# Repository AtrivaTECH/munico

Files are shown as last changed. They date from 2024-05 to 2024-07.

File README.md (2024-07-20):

# μNico
All files for the μNico series of boards!
1 - Copy

## Licensing
oshw_facts

## Tools Utilised

kicad-1

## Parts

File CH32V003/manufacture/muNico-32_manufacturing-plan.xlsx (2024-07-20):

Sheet: BOM-muNico
Sno | Part | Qty | Total | Cost | Total Cost | Supplier
1 | Ch32V003 | 1 | 120 | 31.9 | 3828 | Hubtronics
2 | Green LED 0603 | 1 | 120 | 0.48 | 57.6 | Ktron
3 | Resistor | 1 | 120 | 0.16 | 19.2 | Ktron
4 | AMS1117 | 1 | 120 | 2.98 | 357.6 | Ktron/Kasturi Electrosales | Costs are in INR unless mentioned.
5 | ressitor-usb | 1 | 120 | 0.16 | 19.2 | Ktron
6 | 2.5 Headers | 2 | 240 | 5.5 | 1320 | Ktron
7 | Bootsel SW | 1 | 120 | 20 | 2400 | DK
 |  | TOTAL |  |  | 8001.6
 |  | Per Piece |  |  | 66.68

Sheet: muNico Cost split
 |  | Cost per muNico |  |  | Note
Sno | Item | Cost/piece | QTY | Amount | 120 pieces is minimum as cost is approprably lower at said cost.
1 | Components | 66.68 | 120 | 5601.6
2 | PCB | 46.01666667 | 120 | 5522 | PCB Made locally at PCB Power, Gujarat | LEGEND
3 | Assembly | 20 | 120 | 2400 |  |  | Can Be ignored
4 | ESD Cover | 2.5 | 120 | 300 |  |  | Raw Costs
5 | Sticker | 5 | 120 | 600 |  |  | Set cost and calculations
6 | Stencil | 10 | 120 | 1200 | Cost of one stencil is split across 120 devices |  | Cost in USD per piece including profits, etc etc
 | Cost | 150.1966667 |  | 15623.6 | Estimated cost of manufacture for muNico boards alone |  | Important Note
 | NRE | 3.003933333 |  |  |  |  | Generic Point of note.
 | NET Cost of Manufacture | 153.2006 |  |  |  | Costs are in INR unless mentioned.
 | Expected Cost | 220
 | Cost to be Set | 335
 | Profit % for set | 118.6675509
 | Profit for expected % | 43.60257075
 | Cost after MarkUp | 291.11
 | USD $ per piece (Cost that is set. Not cost of manufacture) | $4.03

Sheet: Cost Allocation
S No | Part/Service | Cost Allocated | Total | QTY | Note
1) | Raw Parts | ₹8002.00 | ₹8002.00 | 120 | 120 pieces chosen for appropriate price ratio.
2) | PCBs (H Extender) | ₹4460.00 | ₹4460.00 | 60
3) | PCBs muNico | ₹5522.00 | ₹5522.00 | 120
4) | muNico Assembly | ₹2400.00 | ₹2400.00 | 120
5) | Packaging-ESD Covers | ₹300.00 | ₹300.00 | 120 |  | Costs are in INR unless mentioned.
6) | Packaging- Box * | ₹1000.00 | ₹1000.00 | 50 | Only Applicable to bundles (variable cost) Approx ₹20 per bx
7) | Sticker/Card for muNico Pack) | ₹600.00 | ₹600.00 | 120 | Raw Material
8) | Assembly Stencil | ₹1200.00 | ₹1200.00 | 1 | For Assembly of each muNico board
9) | WCH LinkEs | ₹14000.00 | ₹14000.00 | 20 | To obtain minimum quantity of programmers. If number required will be lesser than amount specified here, excess amount will be re-invested.
10) | Printing of sticker | ₹2600.00 | ₹2600.00 | 120+20 | Printing on cards+stickers
11) | Customs Clearance/White paper/Shipping | ₹10000.00 | ₹10000.00 |  | To Cover Shipping from India to US, customs and possible extra charges during export
12) | Emergency Costs | ₹8000.00 | ₹8000.00 |  | For covering any damaged parts/PCBs/IC's/ Covers/Boxes ~15%
14) | RoHS Compatible lead free paste | ₹2500 | ₹2500.00
 | TOTAL |  | ₹60584.00 |  | Includes final costs for both munico boards and bundles
 | Total in USD |  | $738.83 | Total Campaign cost excluding any cuts.
 |  |  |  |  | NOTE: Costs of Shipping and Customs will lower core campaign cost if handled partially/fully by Mouser
 |  |  |  |  | NOTE3: If RoHS or CE/UKCA is considered although a development board, then an additional 150USD to RoHS (via SGS) and 400,000 INR is required for UKC/CE and 500,000 INR for FCC. As per quote from SGS and TUV SUD.

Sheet: Bundles
BUNDLE 1 (Starter) * |  |  |  |  | BUNDLE 2 (Hobbyist) * |  |  |  |  | BUNDLE 3 (Developer) |  |  |  |  | BUNDLE 4 (Developer +) |  |  |  |  | BUNDLE 5 (Professional)
S No | Part | Qty | MRP | Cost | S No | Part | Qty | MRP | Cost | S No | Part | Qty | MRP | Cost | S No | Part | Qty | MRP | Cost | S No | Part | Qty | MRP | Cost
1 | muNico | 1 | 335 | 335 | 1 | muNico | 2 | 670 | 670 | 1 | muNico | 2 | 670 | 670 | 1 | muNico | 4 | 1340 | 1300 | 1 | muNico | 10 | 3350 | 3200
2 | muNico Extender | 1 | 80 | 80 | 2 | muNico Extender | 1 | 80 | 80 | 2 | muNico Extender | 1 | 80 | 80 | 2 | muNico Extender | 2 | 160 | 80 | 2 | muNico Extender | 3 | 240 | 200
 |  |  |  |  |  |  |  |  |  | 3 | WCH link E | 1 | 700 | 700 | 3 | WCH link E | 1 | 700 | 700 | 3 | WCH link E | 1 | 700 | 700
Total Cost(Excluding Profits and Additionals) |  |  |  | 415 | Total Cost(Excluding Profits and Additionals) |  |  |  | 750 | Total Cost(Excluding Profits and Additionals) |  |  |  | 1450 | Total Cost(Excluding Profits and Additionals) |  |  |  | 2080 | Total Cost(Excluding Profits and Additionals) |  |  |  | 4100
Final Cost |  |  |  | 500 | Final Cost |  |  |  | 832 | Final Cost |  |  |  | 1664 | Final Cost |  |  |  | 2412 | Final Cost |  |  |  | 4574
USD |  |  |  | $6 | USD |  |  |  | $10 | USD |  |  |  | $20 | USD |  |  |  | $29 | USD |  |  |  | $49.29
CS Share | 12% | 0.72 |  |  | CS Share | 12% | 1.2 |  |  | CS Share | 12% | 2.4 |  |  | CS Share | 12% | 3.48 |  |  | CS Share | 12% | 5.9148
Final Cost (Incl Profits and Additionals) USD** |  |  |  | 6.72 | Final Cost (Incl Profits and Additionals) USD |  |  |  | 11.2 | Final Cost (Incl Profits and Additionals) USD |  |  |  | 22.4 | Final Cost (Incl Profits and Additionals) USD |  |  |  | 32.48 | Final Cost (Incl Profits and Additionals) USD |  |  |  | 55.2048
 |  |  | Costs are in INR unless mentioned.
 |  |  | * Bundle 1 and 2 may not be available in crowdfunding as they are low margin for possible distribution possibilities. In that Case, Bundle 3 Shall be renamed as Hobbyist.
 |  |  | ** This cost is assuming CS takes a cut per product. If the cut is net from the total campaign cost, caluclations will change. Or if CS takes a flat cost due to nature of campaign, cost will vary.

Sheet: Timeline
Tentative dates maximum by which processes must start/end. This is to accommodate around certain pre-set events.
S No | Task | Start Date | End Date | Deviation | Actual End Date | Note
1) | muNico Design | 2024-05-10 | 2024-05-20 | 1 Day Early | 2024-05-19 | Design process in KiCad
2) | muNico Prototype 1 | 2024-05-20 | 2024-05-31 | 1 Day Early | 2024-05-30 | First Prototyping of Board.
3) | prototype Testing | 2024-05-31 | 2024-06-01 | 2 Days Early | 2024-05-30 | Testing of First Prototype design
4) | Firmware/Examples Development | 2024-06-05 | 2024-06-17 | On Time Start | NaN
5) | Documentation | 2024-06-11 | 2024-06-23 | 2 Days Late Start | NaN | Tentative first edition publication date: 15-Jun Tentative Final Edition Publication Date: 25-Jun
6) | CS Campaign selection | 2024-08-10 | NaN | NaN | NaN | Tentative date by which product must be selected by CS. Earlier the better. This will help decide the next steps to be taken depending on decision
7) | Product Shipment to CS for testing Etc | 2024-08-15 | NaN | NaN | NaN | Product Shipment to CS for testing/Photogrpahy etc if necessary to be done maximum before set date.
8) | muNico Example Video (4) (or) split into Quick Start Guides | 2024-08-15 | 2024-08-17 | NaN | NaN | 4 Separate videos going in-depth into each programming and application method shall be made
9) | Examples- Video Production | 2024-08-17 | 2024-08-18 | NaN | NaN
 | Campaign | 2024-08-17 | NaN | NaN | NaN | Date by which campaign must start. To ensure timely completion
10) | First Production Run | 1 Day after campaign | 7 Days after Campaign | NaN | NaN | Production/Assembly of first lot of muNicos.Includes assembly overtime
11) | Accessories Order Run | 8 Days After | 10 Days After | NaN | NaN | All peripherals including Boxes, Covers etc that are to be ordered.
12) | Packaging Completion | 11 Days After | 15 Days After | NaN | NaN | Final Packaging of all goods in respectiove packaging to be completed.
13) | Shipment to Mouser | 16 Days After | NaN | NaN | NaN | Final Shipment Date (Tentative)
 | NOTE: CE/UKCA/FCC is not considered as it is a developnment board and not a commerical device meant for daily use or anything similar. Hence its cost and additionals are not considered.
 |  | Preferably Red-Tape Etc concludes before second week of July and does not extend. | Point 10 onwards are just tentative dates. These might change depending on no of orders and more. | NOTE: Marketing and promotional will happen parallely

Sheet: differentiation
Feature | muNico | CH32V003 Development Board | CH32V003 EVT | CH32V003 core demo board
MFR | AtrivaTECH | nanoDyne | WCH | WeAct
Chipset | CH32V003F4P6 | CH32V003F4U6 | CH32V003F4P6 | CH32V003F4U6
Intended Use | Portable Hardware hacking/USB control | Prototyping | Prototyping | Cheap prototyping
USB Port | USB A | USB C | USB C (power Only) | USB C (power Only)
Data | Yes | Yes | No | No
Dimensions | 19*14.5mm | 16*26mm | 39*45mm | 17.78*30.48mm |  | Legend
Clock | 2Mhz (Can be Expanded) | 12Mhz | 12 Mhz | 2Mhz (No expansion) |  |  | Pros
USB Host Capability | Yes | Yes | No | No |  |  | Not a Pros
Voltage Regulator | 3.3V (V-IN Capability) | 3.3V | No | No |  |  | Cons
External Switch (programmable) | Yes | Yes | No | No
External Enclosure | Yes (Additional) | No | No | No
Documentation | Custom baord specific documentation with use-cases, how-to guides and quick start guide | Limited to GitHub and Docs provided by WCH | No (Development board specific guides) | No documentation
Open Source | Yes OSHW IN53 | Yes | Yes (Limited to Schematic) | No direct linking to board files
Link | muNico 32 - by AtrivaTECH (https://atrivatech.com/munico-32/) | AlexanderMandera/CH32V003-USB-DevBoard: USB-capable Development Board for the CH32V003 microcontroller (github.com) (https://github.com/AlexanderMandera/CH32V003-USB-DevBoard) | CH32V003 Development Board Kit 32-bit general-purpose RISC-V MCU Functional application assessment (aliexpress.com) (https://www.aliexpress.com/item/1005005269690018.html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) | WeAct Studio CH32V003F4U6 RISC-V Low Power Core Demo Board - Robu.in | Indian Online Store | RC Hobby | Robotics (https://robu.in/product/weact-studio-ch32v003f4u6-risc-v-low-power-core-demo-board/) | ghgh
Cost | $4.03 | $4.68 | $3.21 | $1.43

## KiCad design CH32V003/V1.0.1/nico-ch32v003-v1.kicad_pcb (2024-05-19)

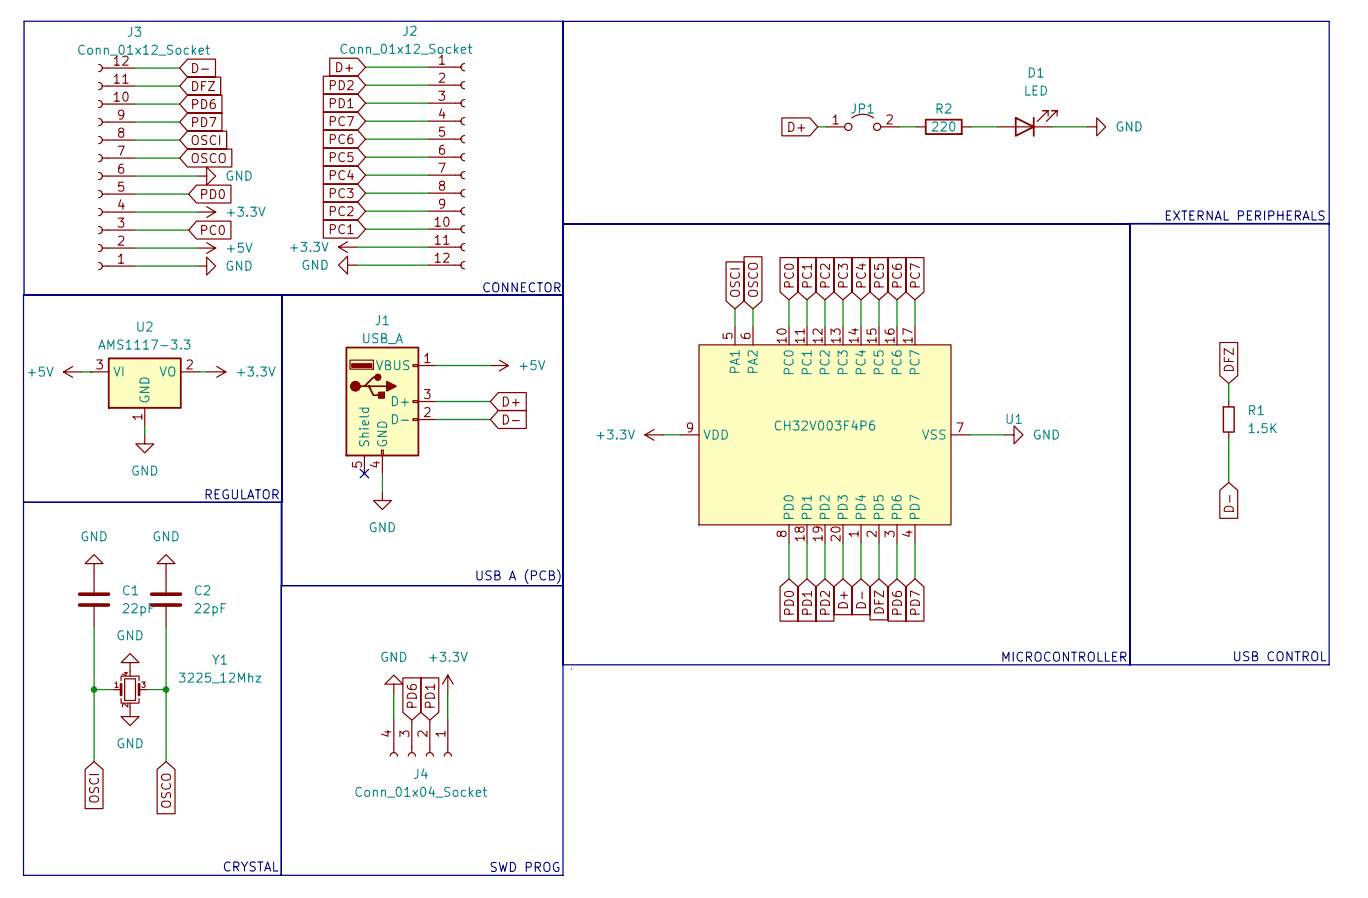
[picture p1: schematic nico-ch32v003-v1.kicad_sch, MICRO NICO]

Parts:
C1, C2: 22pF; C_0402_1005Metric_Pad0.74x0.62mm_HandSolder
D1: LED; LED_0603_1608Metric
J1: USB_A; usb-PCB
J2, J3: Conn_01x12_Socket; pads-1*12
J4: Conn_01x04_Socket; pads__1x04
JP1: Jumper_2_Open; jumper-2-open
R1: 1.5K; R_0402_1005Metric_Pad0.72x0.64mm_HandSolder
R2: 220; R_0402_1005Metric
U1: CH32V003F4P6; TSSOP-20_4.4x6.5mm_P0.65mm
U2: AMS1117-3.3; SOT-223-3_TabPin2
Y1: 3225_12Mhz; Crystal_SMD_3225-4Pin_3.2x2.5mm

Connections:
+3.3V: J2.11, J3.4, J4.1, U1.9 (VDD), U2.2 (VO)
+5V: J1.1 (VBUS), J3.2, U2.3 (VI)
D+: J1.3 (D+), J2.1, JP1.1 (A), U1.20 (PD3)
D-: J1.2 (D-), J3.12, R1.2, U1.1 (PD4)
DFZ: J3.11, R1.1, U1.2 (PD5)
GND: C1.1, C2.1, D1.1 (K), J1.4 (GND), J2.12, J3.1, J3.6, J4.4, U1.7 (VSS), U2.1 (GND), Y1.2, Y1.4
unnamed: D1.2 (A), R2.2
unnamed: JP1.2 (B), R2.1
OSCI: C1.2, J3.8, U1.5 (PA1), Y1.1
OSCO: C2.2, J3.7, U1.6 (PA2), Y1.3
PC0: J3.3, U1.10 (PC0)
PC1: J2.10, U1.11 (PC1)
PC2: J2.9, U1.12 (PC2)
PC3: J2.8, U1.13 (PC3)
PC4: J2.7, U1.14 (PC4)
PC5: J2.6, U1.15 (PC5)
PC6: J2.5, U1.16 (PC6)
PC7: J2.4, U1.17 (PC7)
PD0: J3.5, U1.8 (PD0)
PD1: J2.3, J4.2, U1.18 (PD1)
PD2: J2.2, U1.19 (PD2)
PD6: J3.10, J4.3, U1.3 (PD6)
PD7: J3.9, U1.4 (PD7)

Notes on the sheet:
USB A (PCB)
SWD PROG
REGULATOR
CONNECTOR
CRYSTAL
EXTERNAL PERIPHERALS
MICROCONTROLLER
USB CONTROL

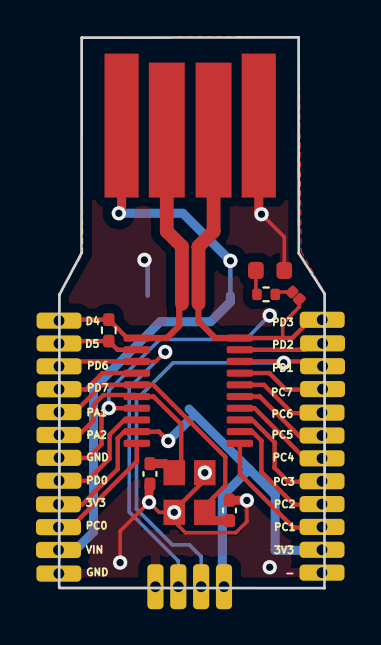
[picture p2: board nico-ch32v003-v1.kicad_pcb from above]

Board: 2 copper layers, 14.7 x 30.6 mm, 13 parts (1 on the bottom side), 23 nets.

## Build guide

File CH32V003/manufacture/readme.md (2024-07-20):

Contains all details of how first batch is going to be manufactured. Only for CS reference. Only important information to be retained if chosen.

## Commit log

2024-05-19 KiCad Files for V1
    [nico-ch32v003-v1.kicad_pcb, nico-ch32v003-v1.kicad_sch]
2024-05-19 Gerber Files for V1 Micro nico
    [nico-ch32v003-v1-B_Cu.gbr, nico-ch32v003-v1-B_Mask.gbr, nico-ch32v003-v1-B_Paste.gbr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]
2024-05-19 All files for 1.0.1 uploaded.
    File directory format changed.
    [nico-ch32v003-v1.kicad_pcb, nico-ch32v003-v1.kicad_sch]
2024-05-19 1.0.1 gerbers
    [nico-ch32v003-v1-B_Cu.gbr, nico-ch32v003-v1-B_Mask.gbr, nico-ch32v003-v1-B_Paste.gbr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]
